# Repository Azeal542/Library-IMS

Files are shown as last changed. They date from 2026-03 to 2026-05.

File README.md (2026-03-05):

# Raspberry Pi setup

Currently the Library checkout system is running on 8GB models of the Raspberry Pi 4 set up with 16GB Optane SSDs.

### Part list

<table border="0" cellpadding="0" cellspacing="0" id="bkmrk-rfid-rc522-reader-1-" style="border-collapse: collapse; width: 205px; height: 165.781px;" width="204"><colgroup><col style="width: 140px;" width="140"></col><col style="width: 64px;" width="64"></col></colgroup><tbody><tr style="height: 29.7969px;"><td height="20" style="height: 29.7969px; width: 105pt;" width="140">RFID RC522 reader</td><td align="right" style="width: 48pt; height: 29.7969px;" width="64">1</td></tr><tr style="height: 29.7969px;"><td height="20" style="height: 29.7969px;">POE Splitter</td><td align="right" style="height: 29.7969px;">1</td></tr><tr style="height: 29.7969px;"><td height="20" style="height: 29.7969px;">M.2 NVMe adapter</td><td align="right" style="height: 29.7969px;">1</td></tr><tr style="height: 29.7969px;"><td height="20" style="height: 29.7969px;">Optane SSD</td><td align="right" style="height: 29.7969px;">1</td></tr><tr style="height: 46.5938px;"><td height="20" style="height: 46.5938px;">Female to Female jumper cables</td><td align="right" style="height: 46.5938px;">7

</td></tr><tr><td>7mm Thickness Embedded Heatsink with Fan</td><td>1

</td></tr><tr><td>3D printed Case</td><td>1

</td></tr></tbody></table>

## Setup process

### Image SD Card

1. Download and install the Raspberry Pi Imager  
    [https://downloads.raspberrypi.com/imager/imager\_latest.exe](https://downloads.raspberrypi.com/imager/imager_latest.exe)
2. Select the correct Raspberry Pi device
3. Select Raspberry Pi OS (64-bit)
4. Select the SD card
5. Enter hostname as \[Location\]Library
6. Set Localization
7. Set Username to kfheadstart
8. Set the password and add it to an entry in Bitwarden
9. Connect to the desired WiFi
10. Turn on SSH using password authentication
11. Ensure Raspberry Pi connect is set to off
12. Write to SD

### Assembly

GPIO diagram reference  
[https://pinout.xyz/](https://pinout.xyz/)

1. Insert imaged SD card into the Raspberry Pi
2. Cut thermal pads to size for CPU and RAM
3. Place cut thermal pads on CPU and RAM
4. Press and hold heatsink then flip Raspberry Pi to the bottom up
5. Screw in 7mm standoffs into the heatsink from the bottom.
6. Plug fan cable red side into pin 4 and black side into pin 6
7. Install Optane SSD into NVME adapter
8. Flip RasPi over so standoffs are facing up
9. Align NVME adapter holes with the standoffs with the SSD on the top
10. Screw in additional 7mm standoffs through the NVME adapter
11. Align plexiglass holes with standoffs then insert screw it in to the standoffs.
12. Flip RasPi over to see the top of the heatsink
13. Insert USB into the bottom port of the middle RasPi USB port and the NVME adapter

### Configuration

1. Boot RasPi and login
2. Run the following commands
   ```bash
    sudo apt update
    sudo apt upgrade -y
    mkdir Library
    cd Library
    git clone https://github.com/Azeal542/Library-IMS
    ./Library-IMS/builder.sh
    ```
4. Run sudo raspi-conifg
5. Select Interfacing options and press enter
6. Select SPI and enable it
7. Place the API key for Snipe-IT at <div><div>/home/kfheadstart/Documents/api.txt</div></div>
8. Run the SD card copier utility and duplicate the SD card to the SSD
9. Shut down the Raspberry Pi and remove the SD card
10. Boot the RasPi and verify that it is now booting from the SSD

### Final Assembly

1. Insert Raspberry Pi Assembly into the bottom half of the case
2. **SDA** connects to **Pin 24**
3. **SCK** connects to **Pin 23**
4. **MOSI** connects to **Pin 19**
5. **MISO** connects to **Pin 21**
6. **GND** connects to **Pin 20**
7. **RST** connects to **Pin 22**
8. **3.3v** connects to **Pin 17**
9. Carefully slide RFID board into the slot in the lid of the case
10. Close the lid
11. Assembly is now complete

### Final Test

1. Run the application shortcut on the desktop to ensure the application boots
2. Test the ID reader by tapping your ID on the top of the case
3. Test Check-in and Check-out features to verify everything is working

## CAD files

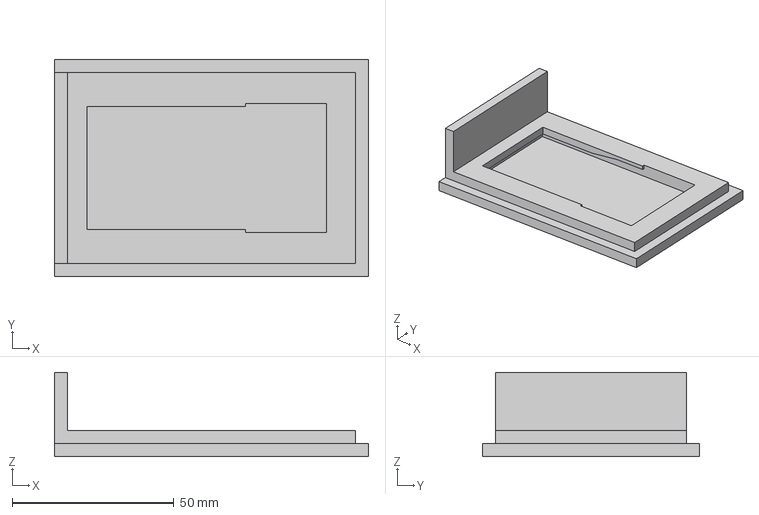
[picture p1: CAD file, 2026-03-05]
Lid v3.3mf
97.0 x 67.0 x 26.0 mm

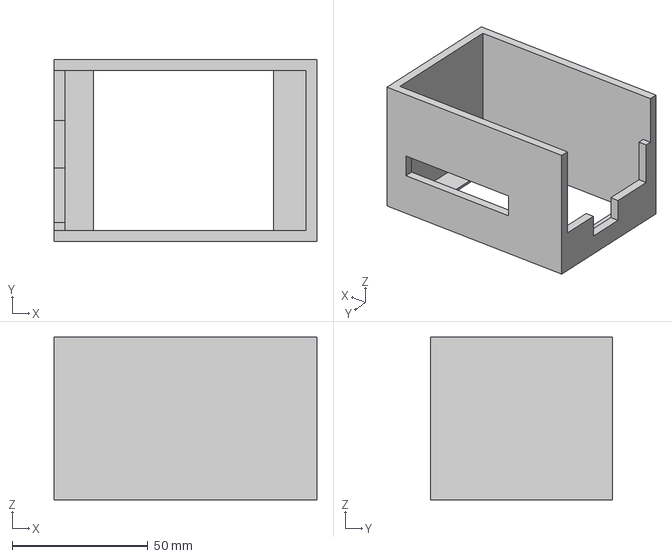
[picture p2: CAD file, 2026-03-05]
Chassis v4.3mf
97.0 x 67.0 x 60.0 mm

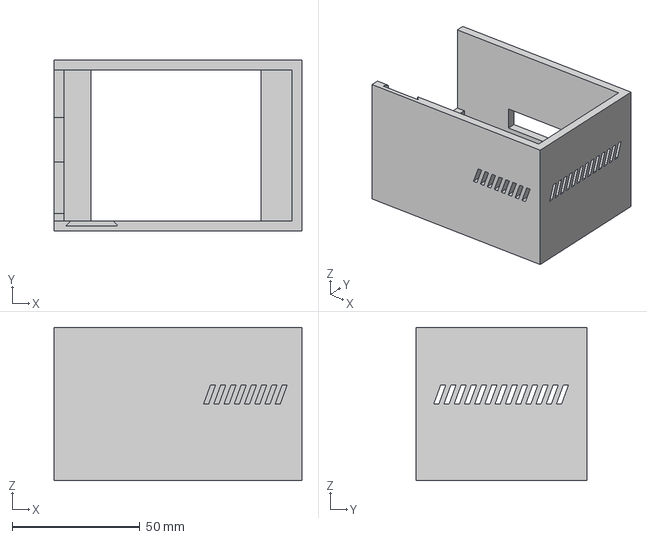
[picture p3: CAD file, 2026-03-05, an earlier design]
Case design archive/chassis v5.3mf
97.0 x 67.0 x 60.0 mm

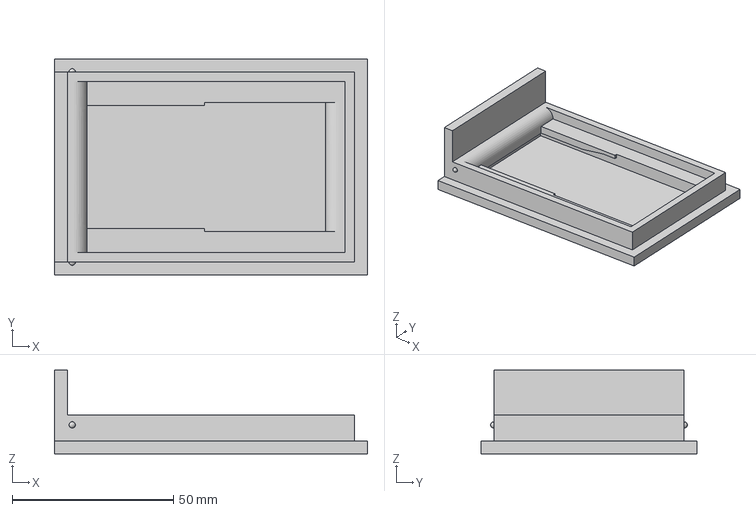
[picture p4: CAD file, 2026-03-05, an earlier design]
Case design archive/lid v5.3mf
97.0 x 67.0 x 26.0 mm

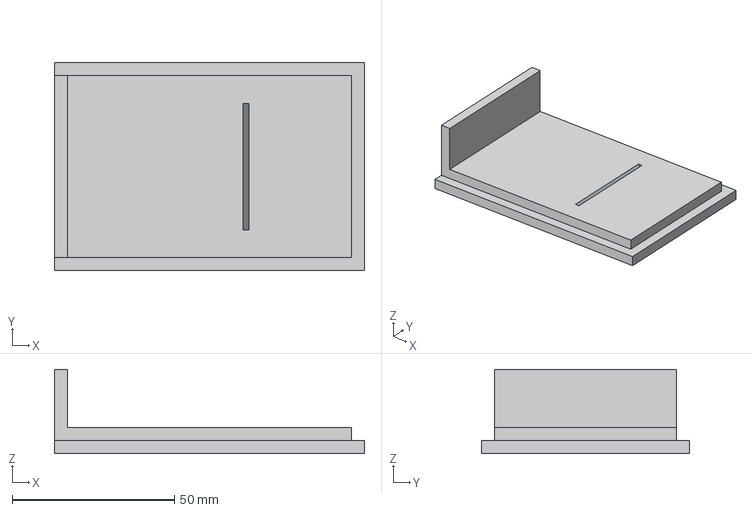
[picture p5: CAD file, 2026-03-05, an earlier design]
Case design archive/Lid v2.3mf
95.5 x 64.0 x 26.0 mm

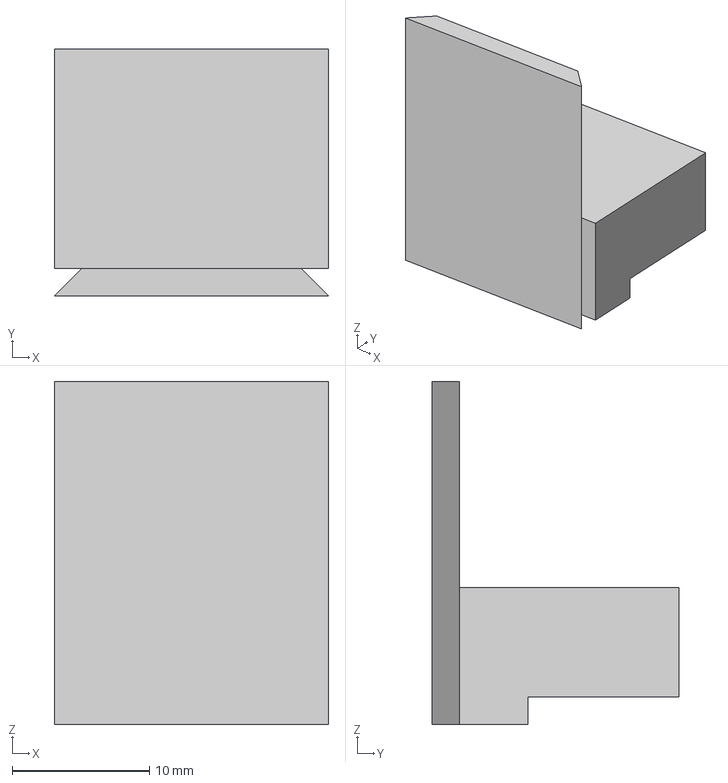
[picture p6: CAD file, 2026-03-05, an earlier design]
Case design archive/Wedge v1.3mf
20.0 x 18.0 x 25.0 mm

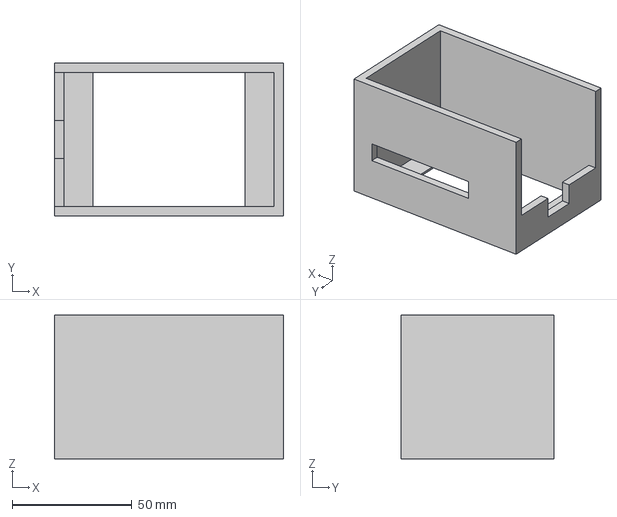
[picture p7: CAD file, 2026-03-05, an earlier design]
Case design archive/Chassis v2.3mf
95.5 x 64.0 x 60.0 mm

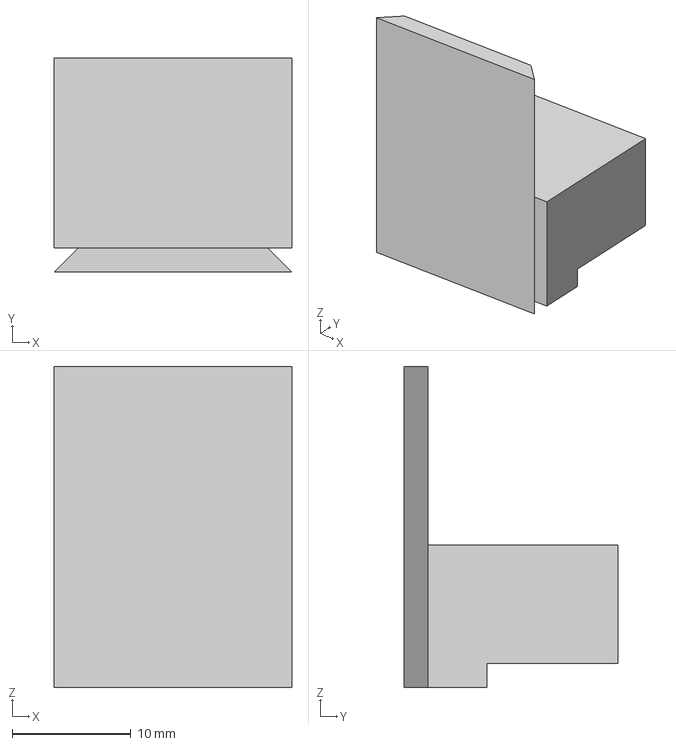
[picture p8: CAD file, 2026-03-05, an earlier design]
Case design archive/wedge v2.3mf
20.0 x 18.0 x 27.0 mm

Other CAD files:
Case design archive/Chassis v3.3mf
Case design archive/chassis v6.3mf
Case design archive/lid v4.3mf

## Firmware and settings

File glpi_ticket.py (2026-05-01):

import requests
import json
import sys
from typing import Optional, Dict, Any
from requests.exceptions import RequestException, Timeout, ConnectionError
import os
from dotenv import load_dotenv

load_dotenv()

glpi = os.getenv('GLPI_API_KEY')
GLPI_URL = os.getenv('GLPI_BASE_URL')
user = os.getenv('GLPI_USER_KEY')

USE_TOKEN_AUTH = True
USER_TOKEN = user

APP_TOKEN = glpi

REQUEST_TIMEOUT = 10

# ============================================================================
# GLPI API CLIENT CLASS
# ============================================================================

class GLPIClient:
    """
    Client for interacting with GLPI REST API v1.
    
    Supports two authentication methods:
    1. User Token: Personal token from user profile (use_token=True)
    2. Username/Password: Direct login with credentials (use_token=False)
    """

    def __init__(self, base_url: str, app_token: Optional[str] = None, 
                 user_token: Optional[str] = None, username: Optional[str] = None, 
                 password: Optional[str] = None):
        """
        Initialize GLPI API client.

        Args:
            base_url: Base URL of GLPI API (e.g., http://glpi.local/apirest.php)
            app_token: Application token (optional)
            user_token: User token for token-based authentication
            username: Username for login-based authentication
            password: Password for login-based authentication
        """
        self.base_url = base_url
        self.app_token = app_token
        self.user_token = user_token
        self.username = username
        self.password = password
        self.session_token = None

    def _get_headers(self, include_session: bool = False) -> Dict[str, str]:
        """
        Build request headers.

        Args:
            include_session: Whether to include session token in headers

        Returns:
            Dictionary of HTTP headers
        """
        headers = {'Content-Type': 'application/json'}

        if self.app_token:
            headers['App-Token'] = self.app_token

        if include_session and self.session_token:
            headers['Session-Token'] = self.session_token

        return headers

    def init_session(self) -> bool:
        """
        Initialize a session with GLPI API.
        Tries user_token first, then falls back to username/password.

        Returns:
            True if session initialized successfully, False otherwise
        """
        try:
            headers = self._get_headers()
            
            # Try user_token first if available
            if self.user_token:
                request_data = {'user_token': self.user_token}
                print("Attempting authentication with user token...")
            # Then try username/password
            elif self.username and self.password:
                request_data = {'login': self.username, 'password': self.password}
                print("Attempting authentication with username/password...")
            else:
                print("No authentication credentials provided.")
                print("  Please set either USER_TOKEN or (GLPI_LOGIN + GLPI_PASSWORD)")
                return False
            
            response = requests.post(
                f"{self.base_url}initSession",
                headers=headers,
                json=request_data,
                timeout=REQUEST_TIMEOUT
            )

            if response.status_code == 200:
                session_data = response.json()
                self.session_token = session_data.get('session_token')
                print("Session initialized successfully.")
                return True
            else:
                print(f"Failed to initialize session: {response.status_code}")
                print(f"  Response: {response.text}")
                return False

        except (ConnectionError, Timeout) as e:
            print(f"Connection error: {e}")
            return False
        except RequestException as e:
            print(f"Request error: {e}")
            return False

    def kill_session(self) -> bool:
        """
        Terminate the current GLPI session.

        Returns:
            True if session terminated successfully, False otherwise
        """
        if not self.session_token:
            return True

        try:
            headers = self._get_headers(include_session=True)
            response = requests.post(
                f"{self.base_url}killSession",
                headers=headers,
                timeout=REQUEST_TIMEOUT
            )

            if response.status_code == 200:
                print("Session terminated successfully.")
                self.session_token = None
                return True
            else:
                print(f"Failed to terminate session: {response.status_code}")
                return False

        except RequestException as e:
            print(f"Error terminating session: {e}")
            return False

    def create_ticket(
        self,
        title: str,
        description: str,
        category_id: Optional[int] = None,
        urgency: int = 3,
        impact: int = 3,
        priority: int = 3,
        type_id: int = 1,
        status: int = 1,
        assigned_to: Optional[int] = None,
        requesters: Optional[list] = None,
        use_session: bool = True
    ) -> Optional[Dict[str, Any]]:
        """
        Create a new ticket in GLPI.

        Args:
            title: Ticket title/name
            description: Ticket description/content
            category_id: ITIL category ID (optional)
            urgency: Urgency level (1-5, default: 3)
            impact: Impact level (1-5, default: 3)
            priority: Priority level (1-5, default: 3)
            type_id: Ticket type ID (1=Incident, 2=Request, default: 1)
            status: Ticket status (1=New, 2=Processing, etc., default: 1)
            assigned_to: User ID to assign ticket to (optional)
            requesters: List of requester user IDs (optional)
            use_session: Whether to use session token (True) or direct auth (False)

        Returns:
            Response dictionary with ticket info if successful, None otherwise
        """
        try:
            # Initialize session if needed and not already done
            if use_session and not self.session_token:
                if not self.init_session():
                    return None

            headers = self._get_headers(include_session=use_session)

            # Build ticket data
            ticket_data = {
                'name': title,
                'content': description,
                'urgency': urgency,
                'impact': impact,
                'priority': priority,
                'type': type_id,
                'status': status
            }

            # Add optional fields
            if category_id is not None:
                ticket_data['itilcategories_id'] = category_id

            if assigned_to is not None:
                ticket_data['_users_id_assign'] = assigned_to

            if requesters:
                ticket_data['_users_id_requester'] = requesters

            # GLPI API v1 expects data wrapped in 'input' array
            request_payload = {'input': [ticket_data]}
            
            response = requests.post(
                f"{self.base_url}Ticket",
                headers=headers,
                json=request_payload,
                timeout=REQUEST_TIMEOUT
            )

            if response.status_code in (200, 201):
                result = response.json()
                # Handle wrapped response format from GLPI
                if isinstance(result, dict) and 'id' in result:
                    ticket_id = result['id']
                    print(f"Ticket created successfully! Ticket ID: {ticket_id}")
                    return result
                else:
                    print(f"Ticket creation request accepted.")
                    print(f"  Response: {json.dumps(result, indent=2)}")
                    return result
            else:
                print(f"Failed to create ticket: {response.status_code}")
                print(f"  Response: {response.text}")
                return None

        except RequestException as e:
            print(f"Request error creating ticket: {e}")
            return None
        
def reportDamagedAsset(assets, location: str, user: str):
    """
    Create a ticket in GLPI for damaged assets.

    Args:
        assets: List of assets
        location: Location where damage occurred
        user: Username reporting the damage
    """
    client = GLPIClient(base_url=GLPI_URL, app_token=APP_TOKEN, user_token=USER_TOKEN)
    ticket_title = f"Damaged Asset Report - {user}"
    
    # Build description with a line for each asset
    description_lines = [f"Location: {location}", ""]
    description_lines.append(f"Reported by: {user}")
    description_lines.append("Affected Assets:")
    
    if isinstance(assets, list):
        for i, asset in enumerate(assets, 1):
            if isinstance(asset, list) and len(asset) == 2:
                asset_name, asset_id = asset
                description_lines.append(f"  {i}. Asset ID: {asset_id} - {asset_name}")
            elif isinstance(asset, dict):
                asset_id = asset.get('id', asset.get('asset_id', 'Unknown'))
                asset_name = asset.get('name', asset.get('asset_name', ''))
                if asset_name:
                    description_lines.append(f"  {i}. Asset ID: {asset_id} - {asset_name}")
                else:
                    description_lines.append(f"  {i}. Asset ID: {asset_id}")
            else:
                # Assume it's just an asset ID
                description_lines.append(f"  {i}. Asset ID: {asset}")
    else:
        # Single asset
        description_lines.append(f"  1. Asset ID: {assets}")
    
    ticket_description = "\n".join(description_lines)

    ticket = client.create_ticket(
        title=ticket_title,
        description=ticket_description,
        urgency=4,
        impact=3,
        priority=4,
        type_id=1,
        status=1,
        category_id=1,
        use_session=True
    )

    if ticket:
        asset_count = len(assets) if isinstance(assets, list) else 1
        print(f"Damage report ticket created for {asset_count} asset(s) reported by {user}.")
        client.kill_session()
        return ticket
    else:
        print(f"Failed to create damage report ticket.")
        client.kill_session()

def main():
    reportDamagedAsset(
        #assets=[{'id': 123, 'name': 'Laptop A'}, {'id': 456, 'name': 'Projector B'}],
        assets=[['Laptop', 123], ['projector', 456]],
        location="Main Office",
        user="John Doe"
    )

if __name__ == "__main__":
    main()

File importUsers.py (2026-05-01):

import csv
from pathlib import Path
import API
import json
import os, random, string
import time
import serial_reader


#input_folder = Path.home() / "Downloads"
input_folder = ("C:\\Users\\CalebPierce\\OneDrive - Klamath Family Head Start\\Documents\\Downloads")
input_file = (input_folder + "\\exportUsers.csv")
global users
users = []
global add
add = []


def password_generator():
    length = 13
    chars = string.ascii_letters + string.digits + '!@#$%^&*()'
    random.seed = (os.urandom(1024))
    password = (''.join(random.choice(chars) for i in range(length)))
    print(f"Generated password: {password}")
    return password

def import_users():
    #with open('output.csv', mode='w', newline='') as outputfile:
        with open(input_file) as csvfile:
            reader = csv.DictReader(csvfile)
            for row in reader:
                if row["userPrincipalName"]:
                    if "onmicrosoft.com" not in row["userPrincipalName"]:
                        addrow = [row[list(row.keys())[1]], row[list(row.keys())[2]]]
                        users.append(addrow)
                        #outputfile.write(f"{addrow[0]},{addrow[1]}\n")
            
def check_users():
    for user in users:
        try:
            time.sleep(0.5)  # Sleep for 0.5 seconds to avoid hitting API rate limits
            result = API.get_User_By_Email(user[1])
            jResult = json.loads(result)
            if jResult["total"] > 0:
                print(f"User {user[0]} with email {user[1]} already exists in Snipe-IT.")
            else:
                add.append(user)
                print(f"User {user[0]} with email {user[1]} does not exist in Snipe-IT and will be added.")
        except Exception as e:
            print(f"An error occurred while checking user {user[0]} with email {user[1]}: {e}")

def create_users():
    scanned_ids = set()
    for user in add:
        time.sleep(0.5)  # Sleep for 0.5 seconds to avoid hitting API rate limits
        print(f"Creating user {user[0]} with email {user[1]} in Snipe-IT.")
        first_name = str(user[0].split()[0])
        last_name = str(user[0].split()[-1])
        email = str(user[1])
        password = str(password_generator())
        username = str(user[0])
        while True:  # Loop until a unique ID is scanned
            id = serial_reader.read_serial_data()
            if id in scanned_ids:
                print(f"ID {id} has already been scanned. Please scan again.")
            else:
                scanned_ids.add(id)
                print(f"Received ID: {id}")
                break  # Exit the loop if the ID is unique
        print(f"Received ID: {id}")
        employee_num = id
        
        #print(first_name, username, password, last_name, email, employee_num)
        API.create_user(first_name, username, password, last_name, email, employee_num)

if __name__ == "__main__":
    import_users()
    check_users()
    create_users()

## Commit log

2026-01-26 Updated API and Frontend
    -Added EmployeeID lookup
    -Fixed applications not closing
    -Added Close functionality for Check in and Check out
    [API.py]
2026-01-27 Check in functionality built
    Added the ability to check in assets as well as fixing sign in and asset lookups.
    [API.py]
2026-01-27 Added Error handling
    Added Error handling for check-in and check-out
    [API.py]
2026-01-28 File selection and some buttons are working
2026-02-12 Document Raspberry Pi setup and assembly process
    Added detailed setup instructions for Raspberry Pi and components.
2026-03-05 Built out asset creation and user import
    [Chassis v4.3mf, Lid v3.3mf, assets.csv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]
2026-03-05 Added case designs
    [Chassis v2.3mf, Chassis v3.3mf, Chassis v4.3mf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]
2026-03-10 Added handler for damaged books and failed login attempts
    [logit.py]
2026-03-17 Removed broken debug line.
    [API.py]
2026-03-18 Updated API key location
    [assets.csv]
2026-05-01 Fixed desktop application location and moved to .env for API keys
    [API.py, glpi_ticket.py]
